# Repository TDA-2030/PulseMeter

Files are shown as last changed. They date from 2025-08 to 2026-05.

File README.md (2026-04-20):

# PulseMeter

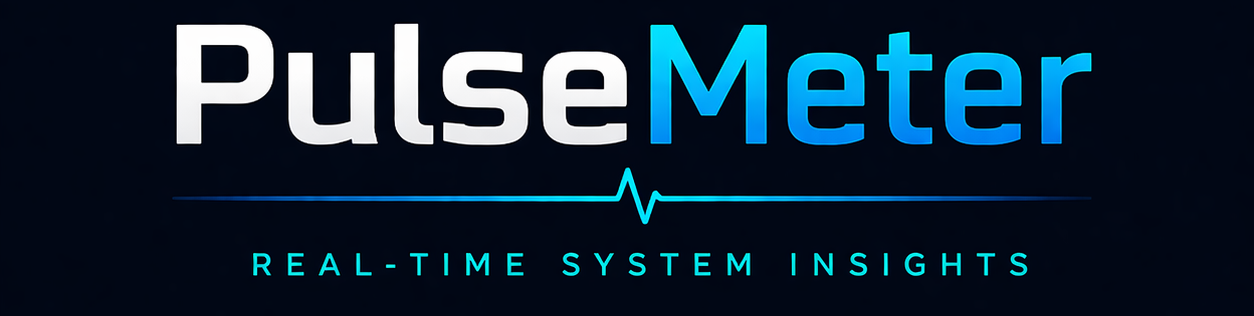
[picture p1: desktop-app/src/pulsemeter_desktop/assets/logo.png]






---

PulseMeter 使用 ESP32-C3 通过 PWM 驱动两个指针式仪表，实时显示 CPU 占用、内存、音频电平等系统指标，做成一个赛博朋克风格的桌面小摆件。

## 开始之前

PulseMeter 由三部分组成：

- [固件说明](firmware/README.md)：烧录 ESP32-C3、从源码构建固件、配置网络
- [桌面客户端](desktop-app/README.md)：本地开发、运行和打包桌面 App
- [硬件资料](hardware/README.md)：结构件和硬件相关文件

## 特性

- **双通道** — 两个独立指针，可分配任意指标组合
- **低延迟** — TCP 直连，PWM 实时响应
- **多指标** — CPU、内存、磁盘、网络、音频电平随意切换
- **桌面客户端** — Tkinter GUI + 系统托盘，最小化后台运行
- **自动发现** — 局域网内自动找到设备，无需手填 IP

## 硬件

| 组件 | 说明 |
|---|---|
| ESP32-C3 开发板 | 主控，运行 TCP 服务器 |
| 指针式仪表头 × 2 | 电压表 / 电流表表头均可，PWM 驱动 |
| 局域网 | 电脑与 ESP32 同一网络 |

## 快速开始

🚀 适合快速体验，浏览器连接开发板后即可直接刷写。

1. 🔥 烧录固件

    <a href="https://espressif.github.io/esp-launchpad/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">
        使用ESP Launchpad一键烧录！
    </a>

    或查看 [固件说明](firmware/README.md)，从源码构建和烧录。

2. 🖥️ 启动桌面客户端

    从 [Releases](https://github.com/TDA-2030/PulseMeter/releases) 下载桌面客户端
    或按照 [桌面客户端说明](desktop-app/README.md) 安装依赖并启动 App。

3. 📶 配置网络

    设备首次启动后，未配置网络会自动进入配置模式，两个指针会来回摆动，此时连接设备的热点 `PulseMeter`，打开浏览器访问 `http://192.168.4.1`，按照提示配置 WiFi 和参数，点击保存后设备会自动重启并连接到 WiFi。

4. 🔗 连接设备

   首次启动后等待设备自动发现，当设备未被发现时，点击设置⚙️ 按钮，在 GUI 中填入设备 IP，点击连接。

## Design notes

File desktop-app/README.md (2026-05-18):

# PulseMeter Desktop App

Python 桌面客户端，用于发现 PulseMeter 设备、选择指标并驱动两根仪表指针。

## 你可以在这里做什么

- 本地开发和调试桌面客户端
- 直接运行源码版本的 App
- 打包为便携可执行文件

## 开发运行

```bash
cd desktop-app
python -m venv .venv
. .venv/bin/activate
pip install -e .
python -m pulsemeter_desktop
```

如果你在 Windows PowerShell 中运行，激活命令改为：

```powershell
.venv\Scripts\Activate.ps1
```

应用会将用户设置保存在系统配置目录中，而不是仓库内。

首次启动后，在 GUI 中填写设备 IP，或等待 mDNS 自动发现；为两根指针分别选择系统指标后即可开始驱动仪表。

## Windows 硬件监控

如果你想在仪表里显示 CPU/GPU/硬盘温度、GPU 负载或风扇转速，可以接入 LibreHardwareMonitor：

1. 安装 Windows 依赖：

```powershell
cd desktop-app
pip install -e .
```

2. 从 LibreHardwareMonitor 官方发布包中取出 `LibreHardwareMonitorLib.dll`，放到固定目录：

```text
desktop-app/src/pulsemeter_desktop/vendor/librehardwaremonitor/LibreHardwareMonitorLib.dll
```

如果发布包里还有 `LibreHardwareMonitorLib.xml`，也建议一起放进去，便于后续查阅传感器说明，但运行时只依赖 DLL。

3. 重新启动应用。Windows 下如果 DLL 成功加载，指标列表里会出现：

- `CPU Temp`
- `CPU Power`
- `CPU Clock`
- `CPU Voltage`
- `GPU Temp`
- `GPU Load`
- `GPU Power`
- `GPU Core Clock`
- `GPU Memory Clock`
- `GPU Memory Load`
- `SSD Temp`
- `Mainboard Temp`
- `Fan Speed`

LibreHardwareMonitor 官方 README 给出的集成方式核心是：

- 创建 `Computer`
- 打开 `IsCpuEnabled` / `IsGpuEnabled` / `IsStorageEnabled` 等开关
- `Open()` 后定期 `Update()` 硬件树并读取 `Sensors`

本项目已经按这个模式封装成可选 provider，并挂进现有 `DataCollector` 轮询流程。

注意：

- 这部分仅在 Windows 上启用。
- 某些主板/风扇/温度传感器需要管理员权限才能读到。
- 如果选中了硬件指标但读不到值，应用会显示 `—` 并在底部提示尝试用管理员权限启动。
- 仓库不会让用户在运行时手动配置 DLL 路径；只认上面的固定 vendor 目录。

## 打包

```bash
cd desktop-app
python scripts/build.py          # 单文件可执行程序
python scripts/build.py --onedir # 目录包，启动更快
```

## 相关文档

- 设备端烧录和源码构建见 [固件文档](../firmware/README.md)
- 项目总览见 [根 README](../README.md)

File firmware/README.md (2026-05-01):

# PulseMeter Firmware

ESP32-C3 固件负责接收桌面端发送的系统指标，并通过 PWM 驱动两根指针式仪表。

## 你可以在这里做什么

- 在线一键烧录到开发板
- 使用 ESP-IDF 从源码构建和刷写固件
- 查看设备端的大致工作方式和引脚分配

## 从源码构建

### 环境要求

- ESP-IDF v5.5
- ESP32-C3 开发板

### 构建与烧录

```bash
cd firmware
idf.py set-target esp32c3
idf.py build
idf.py flash monitor
```

如果已经设置过 target，后续通常只需要执行：

```bash
cd firmware
idf.py build flash monitor
```

## 配置与联调

烧录完成后，设备会运行 TCP 服务，等待桌面客户端连接并发送双通道表针数据。

- 桌面端开发、运行和打包说明见 [桌面客户端文档](../desktop-app/README.md)
- 根项目概览见 [README](../README.md)

## GPIO 引脚

| 功能 | GPIO |
|---|---|
| 仪表 1 PWM | 5 |
| 仪表 2 PWM | 6 |
| 灯带 1 数据 | 4 |
| 灯带 2 数据 | 7 |
| I2C SDA / SCL | 2 / 3 |

说明：

- 两路 RGB 分别对应两条独立 WS2812 灯带
- 当前固件默认控制每条灯带的第 1 个灯珠

## TCP 数据包格式

PulseMeter 使用自定义二进制帧协议，通过 TCP `5000` 端口通信，不再是早期的 5 字节裸数据格式。

### 通用帧结构

所有数值均按大端序编码：

```text
magic[2]  type[1]  seq[1]  len[2]  payload[len]  crc8[1]
```

| 字段 | 长度 | 说明 |
|---|---:|---|
| `magic` | 2 | 固定为 `0x23 0x35` |
| `type` | 1 | 消息类型 |
| `seq` | 1 | 序号；`0` 表示单向发送，不期待响应 |
| `len` | 2 | 负载长度，大端序 |
| `payload` | 可变 | 消息体 |
| `crc8` | 1 | `type ^ seq ^ len_hi ^ len_lo ^ payload...` 的逐字节异或结果 |

### 消息类型

| `type` | 方向 | 含义 |
|---|---|---|
| `0x01` | Host → Device | `MSG_STREAM`，推送两路表针数值，不返回响应 |
| `0x02` | Host → Device | `MSG_READ_REQ`，读取设备参数 |
| `0x03` | Device → Host | `MSG_READ_RSP`，返回参数值 |
| `0x04` | Host → Device | `MSG_WRITE_REQ`，写入设备参数，包括两路 LED RGB |
| `0x05` | Device → Host | `MSG_WRITE_RSP`，返回写入结果 |

### `MSG_STREAM` 实时表针数据

负载固定为 2 字节：

```text
meter1[1]  meter2[1]
```

- `meter1`：第 1 根指针的百分比，范围 `0-100`
- `meter2`：第 2 根指针的百分比，范围 `0-100`
- `seq` 固定为 `0`

示例：

```text
23 35 01 00 00 02 32 64 55
```

含义：

- `23 35`：魔数
- `01`：`MSG_STREAM`
- `00`：单向帧
- `00 02`：负载长度为 2
- `32 64`：两路数据分别为 `50` 和 `100`
- `55`：CRC8

### `MSG_READ_REQ` / `MSG_READ_RSP`

读取请求负载：

```text
param_id[2]
```

读取响应负载：

```text
param_id[2]  status[1]  value[4]
```

### `MSG_WRITE_REQ` / `MSG_WRITE_RSP`

写入请求负载：

```text
param_id[2]  value[4]
```

两路 LED 颜色通过独立参数写入，`value` 采用 `0x00RRGGBB` 打包格式。

- `PARAM_METER1_RGB` 控制 GPIO `4` 上的灯带 1
- `PARAM_METER2_RGB` 控制 GPIO `7` 上的灯带 2

示例：将第 1 路 LED 设置为橙色 `RGB(255, 128, 0)`：

```text
param_id = 0x0020
value    = 0x00FF8000
```

写入响应负载：

```text
param_id[2]  status[1]
```

### 状态码

| `status` | 含义 |
|---|---|
| `0x00` | 成功 |
| `0x01` | 通用错误，例如写入只读参数 |
| `0x02` | 未知参数 ID |

### 参数 ID

| 参数 | ID | 类型 | 说明 |
|---|---:|---|---|
| `PARAM_METER1_MAX_DUTY` | `0x0001` | `uint32` | 仪表 1 的 PWM 占空比上限，可读写 |
| `PARAM_METER2_MAX_DUTY` | `0x0002` | `uint32` | 仪表 2 的 PWM 占空比上限，可读写 |
| `PARAM_MODE` | `0x0003` | `uint8` | 设备模式，可读写 |
| `PARAM_METER1_RGB` | `0x0020` | `uint32` | 仪表 1 LED 颜色，格式 `0x00RRGGBB`，可读写 |
| `PARAM_METER2_RGB` | `0x0021` | `uint32` | 仪表 2 LED 颜色，格式 `0x00RRGGBB`，可读写 |
| `PARAM_METER1_VALUE` | `0x0010` | `uint8` | 仪表 1 当前百分比，只读 |
| `PARAM_METER2_VALUE` | `0x0011` | `uint8` | 仪表 2 当前百分比，只读 |

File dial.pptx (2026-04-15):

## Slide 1

67.8

CPU

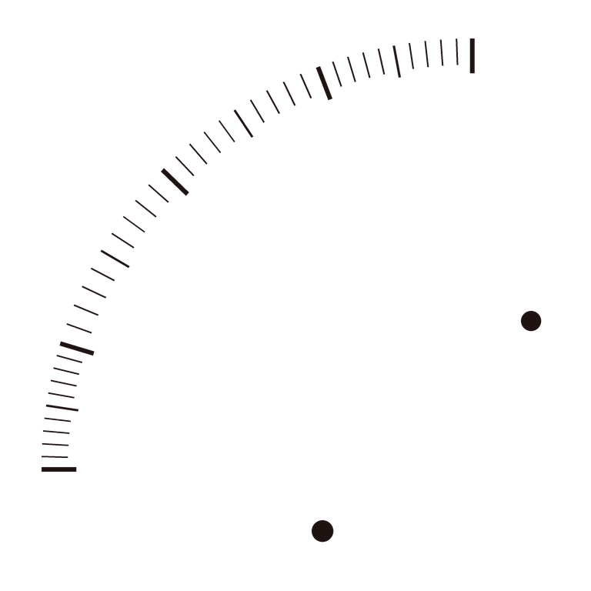
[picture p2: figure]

100

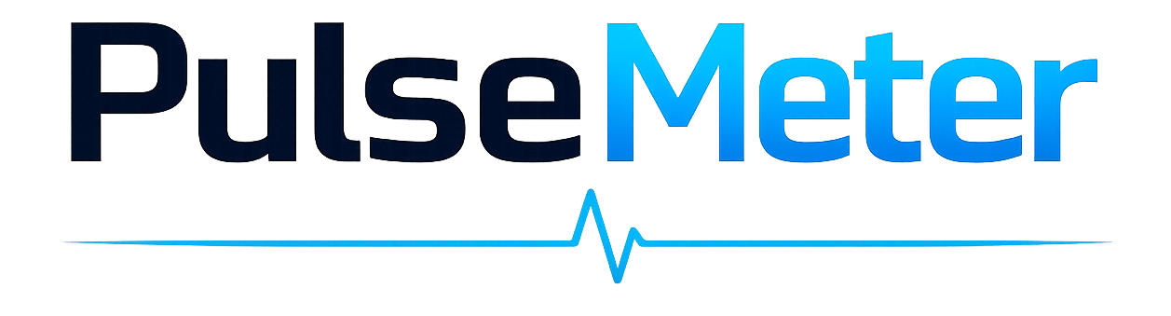
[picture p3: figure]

50

75

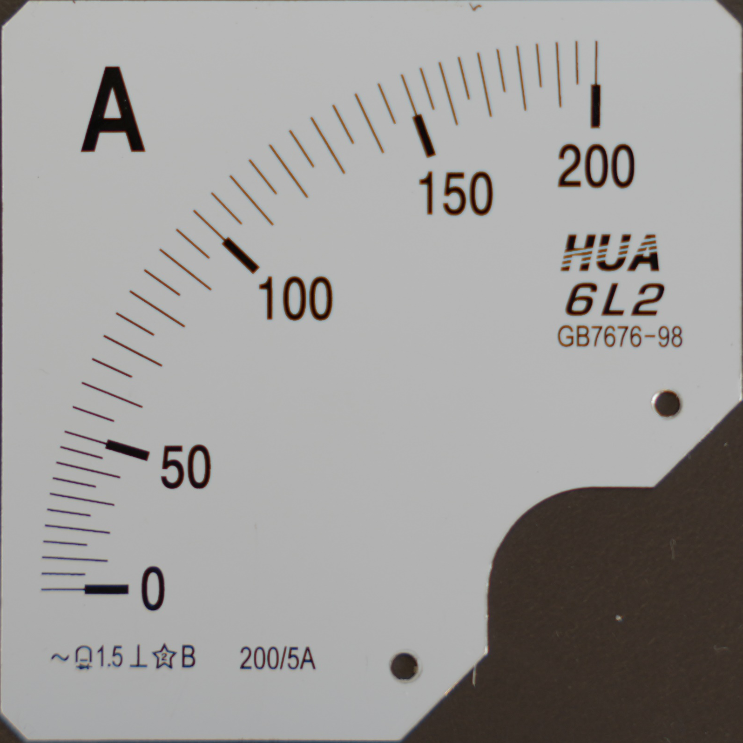
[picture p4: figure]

25

0

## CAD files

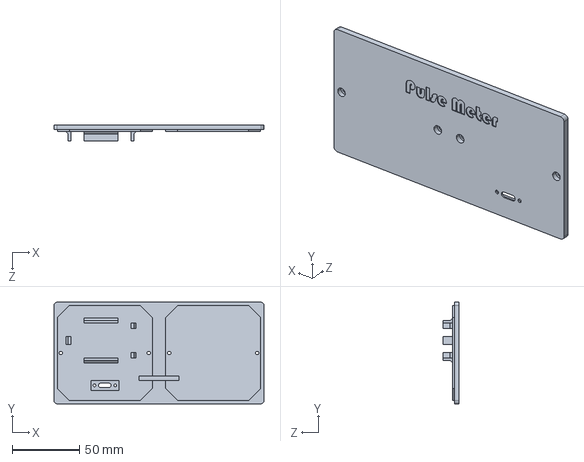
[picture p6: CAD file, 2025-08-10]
hardware/3d/meter-back-panel-double.STEP
156.0 x 75.5 x 12.0 mm

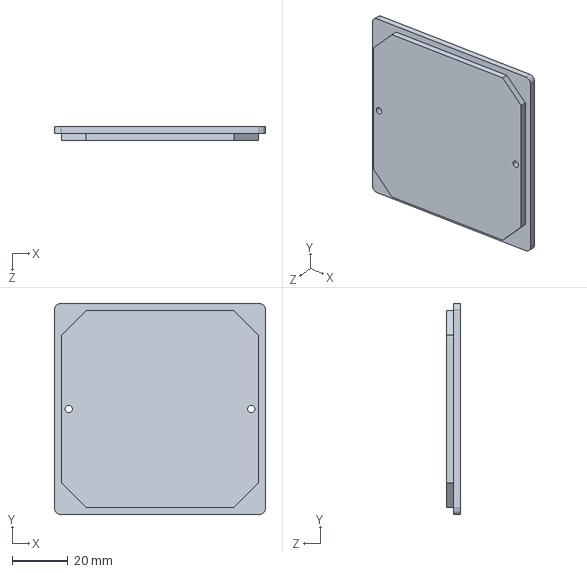
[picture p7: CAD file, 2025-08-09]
hardware/3d/meter-back-panel.SLDPRT
75.5 x 75.5 x 5.00 mm

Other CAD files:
hardware/3d/meter-back-panel-double.SLDPRT

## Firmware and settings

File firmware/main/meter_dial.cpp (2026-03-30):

/* LEDC (LED Controller) basic example

   This example code is in the Public Domain (or CC0 licensed, at your option.)

   Unless required by applicable law or agreed to in writing, this
   software is distributed on an "AS IS" BASIS, WITHOUT WARRANTIES OR
   CONDITIONS OF ANY KIND, either express or implied.
*/
#include <stdio.h>
#include <math.h>
#include <algorithm>
#include "freertos/FreeRTOS.h"
#include "freertos/task.h"
#include "freertos/timers.h"
#include "driver/ledc.h"
#include "esp_timer.h"
#include "esp_err.h"
#include "esp_log.h"
#include "meter_dial.h"
#include "board.h"

static const char *TAG = "motor";

int PWM::channel_cnt = (int) LEDC_CHANNEL_0;

bool PWM::init(int pin1)
{
#define LEDC_TIMER              LEDC_TIMER_0
#define LEDC_MODE               LEDC_LOW_SPEED_MODE
#define LEDC_DUTY_RES           LEDC_TIMER_12_BIT

    ESP_LOGI(TAG, "Initializing PWM channel %d on pin %d", channel_cnt, pin1);
    channel = channel_cnt++;

    // Prepare and then apply the LEDC PWM timer configuration
    ledc_timer_config_t ledc_timer = {
        .speed_mode       = LEDC_MODE,
        .duty_resolution  = LEDC_DUTY_RES,
        .timer_num        = LEDC_TIMER,
        .freq_hz          = (uint32_t)10000,
        .clk_cfg          = LEDC_AUTO_CLK,
        .deconfigure      = false,
    };
    ESP_ERROR_CHECK(ledc_timer_config(&ledc_timer));

    // Prepare and then apply the LEDC PWM channel configuration
    ledc_channel_config_t ledc_channel = {
        .gpio_num       = pin1,
        .speed_mode     = LEDC_MODE,
        .channel        = (ledc_channel_t)channel,
        .intr_type      = LEDC_INTR_DISABLE,
        .timer_sel      = LEDC_TIMER,
        .duty           = 0, // Set duty to 0%
        .hpoint         = 0,
        .sleep_mode     = LEDC_SLEEP_MODE_NO_ALIVE_NO_PD,
        .flags          = {
            .output_invert = 0,
        },
    };
    ESP_ERROR_CHECK(ledc_channel_config(&ledc_channel));
    return 0;
}

void PWM::set_pwm(uint32_t duty)
{
    ledc_set_duty(LEDC_MODE, (ledc_channel_t)channel, duty);
    ESP_ERROR_CHECK(ledc_update_duty(LEDC_MODE, (ledc_channel_t)channel));
}

MeterDial::MeterDial(const char *_name): name(_name)
{

}

void MeterDial::init(int pwm_pin)
{
    pwm = new PWM();
    pwm->init(pwm_pin);
    pwm->set_pwm(0);
    max_duty = 450;
    selfTest();
}

void MeterDial::set_percent(int percent)
{
    int32_t duty = std::clamp(percent, 0, 100);
    duty = duty * max_duty / 100;
    pwm->set_pwm(duty);
}

void MeterDial::enable(bool is_enable)
{


}

void MeterDial::selfTestTimerCallback(TimerHandle_t xTimer)
{
    auto *meter = static_cast<MeterDial *>(pvTimerGetTimerID(xTimer));
    MeterDial::selfTest_ctx_s *st = &meter->selfTestCtx;

    const float accelUp     = 0.2f;  // 上升加速度
    const float accelDown   = 0.2f; // 下降加速度（减速）

    if (st->state == MeterDial::selfTest_ctx_s::ACCEL_UP) {
        // 加速度增加速度
        st->velocity += accelUp;
        st->currentValue += st->velocity;

        if (st->currentValue >= 100) {
            st->currentValue = 100;
            st->velocity *= -1; // 到顶速度反转
            st->state = MeterDial::selfTest_ctx_s::SLOW_DOWN;
        }
        meter->set_percent(st->currentValue);

    } else if (st->state == MeterDial::selfTest_ctx_s::SLOW_DOWN) {
        // 缓慢下降
        st->velocity += accelDown;
        st->currentValue += st->velocity;

        if (st->currentValue <= 8) {
            st->currentValue = 0;
            st->velocity = 0;
            st->state = MeterDial::selfTest_ctx_s::IDLE;
            xTimerStop(st->Timer, 0);
            xTimerDelete(st->Timer, 0);
            st->Timer = nullptr;
        }
        meter->set_percent(st->currentValue);
    }
}

void MeterDial::selfTest()
{
    if (selfTestCtx.Timer != nullptr) {
        xTimerStop(selfTestCtx.Timer, 0);
        xTimerDelete(selfTestCtx.Timer, 0);
    }
    // 创建周期 20ms 的定时器
    selfTestCtx.Timer = xTimerCreate(
                        "SelfTestTimer",
                        pdMS_TO_TICKS(30),
                        pdTRUE,
                        this,
                        &MeterDial::selfTestTimerCallback
                    );
    selfTestCtx.state = MeterDial::selfTest_ctx_s::ACCEL_UP;
    selfTestCtx.currentValue = 0;
    xTimerStart(selfTestCtx.Timer, 0);
}

void MeterDial::waitSelfTestDone()
{
    while (selfTestCtx.state != MeterDial::selfTest_ctx_s::IDLE) {
        vTaskDelay(pdMS_TO_TICKS(30));
    }
}

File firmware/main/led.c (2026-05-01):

/*
 * SPDX-FileCopyrightText: 2026 Espressif Systems (Shanghai) CO LTD
 *
 * SPDX-License-Identifier: Apache-2.0
 */
#include "led.h"

#include <inttypes.h>
#include <stdbool.h>
#include <stdlib.h>

#include "esp_log.h"
#include "led_strip.h"
#include "led_strip_rmt.h"
#include "led_strip_types.h"

#define LED_RMT_RES_HZ (10 * 1000 * 1000)

static const char *TAG = "led";

struct led {
    int gpio;
    uint32_t max_leds;
    led_strip_handle_t strip;
    uint32_t pixel_index;
};

static void led_hsv_to_rgb(uint32_t hue, uint32_t saturation, uint32_t value, uint32_t *red, uint32_t *green, uint32_t *blue)
{
    uint32_t region = 0;
    uint32_t remainder = 0;
    uint32_t p = 0;
    uint32_t q = 0;
    uint32_t t = 0;

    if (red) {
        *red = 0;
    }
    if (green) {
        *green = 0;
    }
    if (blue) {
        *blue = 0;
    }

    if (!red || !green || !blue) {
        ESP_LOGE(TAG, "HSV conversion output pointer is NULL");
        return;
    }

    if (saturation == 0) {
        *red = value;
        *green = value;
        *blue = value;
        return;
    }

    hue %= 360;
    region = hue / 60;
    remainder = ((hue % 60) * 255) / 60;

    p = (value * (255 - saturation)) / 255;
    q = (value * (255 - ((saturation * remainder) / 255))) / 255;
    t = (value * (255 - ((saturation * (255 - remainder)) / 255))) / 255;

    switch (region) {
    case 0:
        *red = value;
        *green = t;
        *blue = p;
        break;
    case 1:
        *red = q;
        *green = value;
        *blue = p;
        break;
    case 2:
        *red = p;
        *green = value;
        *blue = t;
        break;
    case 3:
        *red = p;
        *green = q;
        *blue = value;
        break;
    case 4:
        *red = t;
        *green = p;
        *blue = value;
        break;
    default:
        *red = value;
        *green = p;
        *blue = q;
        break;
    }
}

esp_err_t led_create(int gpio, uint32_t max_leds, uint32_t pixel_index, led_handle_t *out_led)
{
    if (!out_led || max_leds == 0 || pixel_index >= max_leds) {
        ESP_LOGE(TAG, "LED create failed: invalid arguments");
        return ESP_ERR_INVALID_ARG;
    }
    *out_led = NULL;

    led_handle_t led = calloc(1, sizeof(*led));
    if (!led) {
        ESP_LOGE(TAG, "LED create failed: handle allocation failed");
        return ESP_ERR_NO_MEM;
    }

    led_strip_config_t strip_config = {
        .strip_gpio_num = gpio,
        .max_leds = max_leds,
        .led_model = LED_MODEL_WS2812,
        .color_component_format = LED_STRIP_COLOR_COMPONENT_FMT_GRB,
        .flags = {
            .invert_out = false,
        },
    };
    led_strip_rmt_config_t rmt_config = {
        .clk_src = RMT_CLK_SRC_DEFAULT,
        .resolution_hz = LED_RMT_RES_HZ,
        .mem_block_symbols = 0,
        .flags = {
            .with_dma = 0,
        },
    };

    esp_err_t err = led_strip_new_rmt_device(&strip_config, &rmt_config, &led->strip);
    if (err != ESP_OK) {
        ESP_LOGE(TAG, "LED create failed: %s", esp_err_to_name(err));
        free(led);
        return err;
    }

    led->gpio = gpio;
    led->max_leds = max_leds;
    led->pixel_index = pixel_index;

    err = led_strip_clear(led->strip);
    if (err != ESP_OK) {
        ESP_LOGE(TAG, "LED clear after create failed: %s", esp_err_to_name(err));
        led_strip_del(led->strip);
        free(led);
        return err;
    }
    *out_led = led;
    return ESP_OK;
}

esp_err_t led_destroy(led_handle_t led)
{
    if (!led) {
        return ESP_OK;
    }

    esp_err_t err = ESP_OK;
    if (led->strip) {
        err = led_strip_clear(led->strip);
        if (err != ESP_OK) {
            ESP_LOGE(TAG, "LED strip clear before destroy failed: %s", esp_err_to_name(err));
        }

        err = led_strip_del(led->strip);
        if (err != ESP_OK) {
            ESP_LOGE(TAG, "LED strip destroy failed: %s", esp_err_to_name(err));
            free(led);
            return err;
        }
    }

    free(led);
    return ESP_OK;
}

esp_err_t led_set_pixel(led_handle_t led, uint32_t red, uint32_t green, uint32_t blue)
{
    if (!led || !led->strip) {
        ESP_LOGE(TAG, "LED set_pixel failed: invalid led handle");
        return ESP_ERR_INVALID_STATE;
    }

    esp_err_t err = led_strip_set_pixel(led->strip, led->pixel_index, red, green, blue);
    if (err != ESP_OK) {
        ESP_LOGE(TAG, "LED set_pixel failed at index %" PRIu32 ": %s",
                 led->pixel_index, esp_err_to_name(err));
    }
    return err;
}

esp_err_t led_set_pixel_hsv(led_handle_t led, uint32_t hue, uint32_t saturation, uint32_t value)
{
    if (saturation > 255 || value > 255) {
        ESP_LOGE(TAG, "LED set_pixel_hsv failed: saturation and value must be in range 0-255");
        return ESP_ERR_INVALID_ARG;
    }

    uint32_t red = 0;
    uint32_t green = 0;
    uint32_t blue = 0;

    // Convert HSV to RGB because the led_strip driver accepts RGB components.
    led_hsv_to_rgb(hue, saturation, value, &red, &green, &blue);
    return led_set_pixel(led, red, green, blue);
}

esp_err_t led_refresh(led_handle_t led)
{
    if (!led || !led->strip) {
        ESP_LOGE(TAG, "LED refresh failed: invalid led handle");
        return ESP_ERR_INVALID_STATE;
    }

    esp_err_t err = led_strip_refresh(led->strip);
    if (err != ESP_OK) {
        ESP_LOGE(TAG, "LED refresh failed: %s", esp_err_to_name(err));
    }
    return err;
}

esp_err_t led_clear(led_handle_t led)
{
    if (!led || !led->strip) {
        ESP_LOGE(TAG, "LED clear failed: invalid led handle");
        return ESP_ERR_INVALID_STATE;
    }

    esp_err_t err = led_strip_set_pixel(led->strip, led->pixel_index, 0, 0, 0);
    if (err != ESP_OK) {
        ESP_LOGE(TAG, "LED clear failed: %s", esp_err_to_name(err));
        return err;
    }
    return led_refresh(led);
}

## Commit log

2025-08-09 3d: update
    [meter-back-panel-double.SLDPRT, meter-back-panel-double.STEP, meter-back-panel.SLDPRT]
2026-04-03 feat(pulsemeter): replace icon with assets/icon.ico
    Switch tray and window icon from icon.png to assets/icon.ico.
    Update build.py and pulsemeter.spec to bundle assets/ directory
    and reference the new path. Add iconbitmap call for the Tk window.
2026-04-03 chore(build): reduce bundle size via module exclusions
    - Switch --collect-all to --collect-submodules for soundcard and
    zeroconf to skip their test/data files
    - Add --exclude-module list for numpy internals (testing/distutils/
    f2py/random/polynomial/ma), test frameworks (unittest/pytest),
    and unused stdlib (sqlite3/xmlrpc/ftplib/etc.)
    - Sync exclusions into pulsemeter.spec
2026-04-13 Add captive portal probe path compatibility
2026-04-14 Use numpy FIR audio filter
2026-04-15 Poll default speaker and switch loopback device
2026-04-20 chore: clean firmware code
    [partitions.csv]
2026-04-21 fix(app): block rescans while connected and show duplicate-launch
    - prevent device rescans when the app is already connected or connecting
    - ignore fallback scan results that arrive during an in-flight connection
    - show a warning dialog when a second app instance is launched
2026-05-01 feat: add led strip
2026-05-01 Add meter LED protocol and settings controls

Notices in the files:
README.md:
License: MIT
